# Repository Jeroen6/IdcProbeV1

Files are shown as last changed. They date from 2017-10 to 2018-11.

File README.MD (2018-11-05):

# IdcProbeV1
Invasive isolated DC Current probe based on Sensitec CMS3000

## What

This USB 5V powered current sensor should provide an relatively cheap way to safely scope AC or DC current.  
It should provide isolation up to 4 kV (rms), meaning it can measure anywhere in a circuit.

The high bandwidth and accuracy of the Sensitec module made it almost like a normal shunt.

Transfer ratio of the 5A and 15A unit would be 1A:1V and 1A:0.1V respectively.

## Challenges
The challenges involved in this project are powering the Sensitec sensor from a USB port, commonly found on most modern scopes.  
This required a high frequency (1.3 Mhz) DC-DC converter to create positive ands negative 12V for the sensor.  
Several prototypes have shown this is not an easy job, keeping ripple low is difficult with >1 MHz converters.

Due to the capacitance required for the DC-DC converter a high inrush current needs to be reduced on the USB input.

## Progress so far
So far two working prototypes have been made (photo) and used thoroughly this year, it was extremely useful!  
Several important changes to the circuit have been made, both to the DC-DC, the input current, and oscillation prevention on the output with long BNC cables.

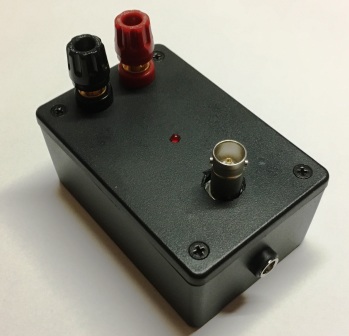
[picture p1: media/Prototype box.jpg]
photo of prototype
  
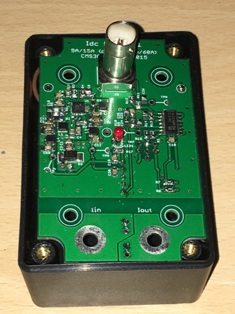
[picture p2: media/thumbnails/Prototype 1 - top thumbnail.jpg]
photo of prototype

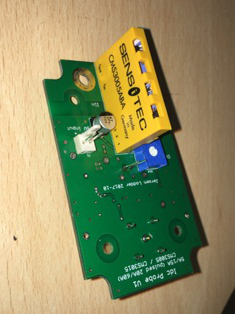
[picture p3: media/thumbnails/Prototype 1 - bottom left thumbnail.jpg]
photo of prototype
  
*(high-res in media folder)*

However, when (winter)time came to continue this project sad news arrived.  
[Sensitec discontinued the CMS and CDS current sensor families][1], with the [CFS1000][2] chip as alternative.

## Future
The CFS1000 is a more versatile product. Which is an advantage, but not if you required on the engineering and factory calibration of the CMS3000.
The CFS series requires development of an external sensing busbar and calibration procedure, both exceed my initial intended complexity of this project. But I might change my mind.

I will probably not persue development of this project, apart from assembling a few units for peronal use.  

*If someone has ideas to revive this project, let me know (make an issue or something)*

[1]: https://github.com/Jeroen6/IdcProbeV1/blob/master/doc/Sensitec%20-%20CMS3000%20-%20Current%20sensor%20discontinuation%20notice.pdf
[2]: https://github.com/Jeroen6/IdcProbeV1/blob/master/doc/Sensited%20-%20CFS1000%20-%20%20Integrated%20MagnetoResistive%20Current%20Sensor.pdf

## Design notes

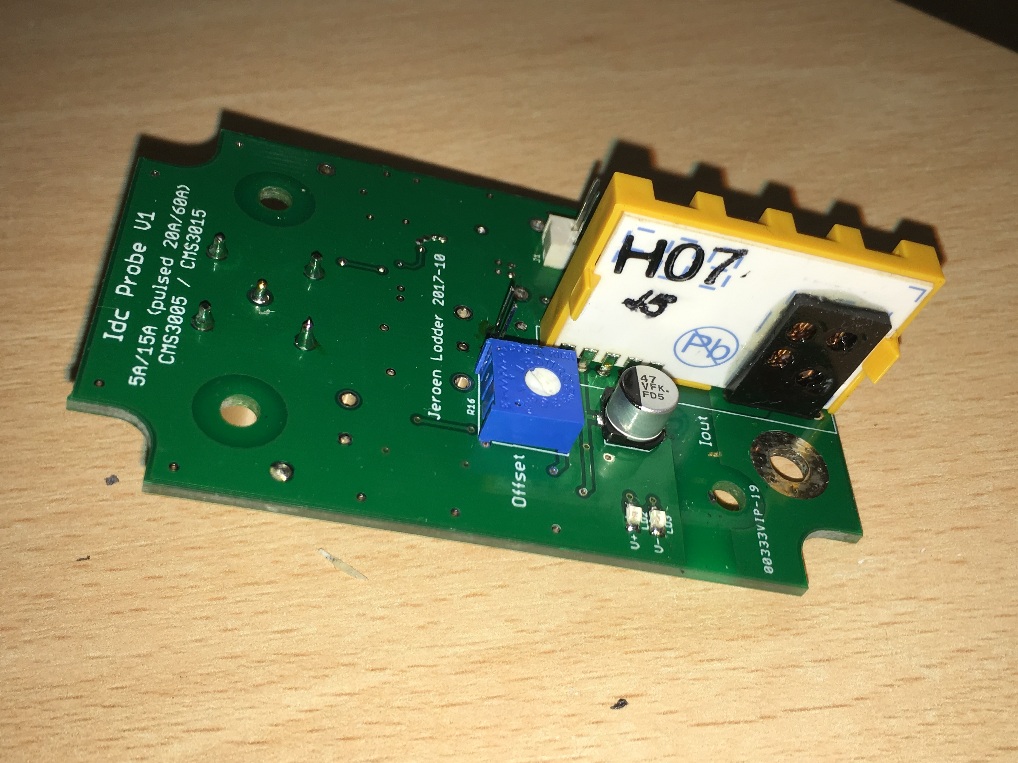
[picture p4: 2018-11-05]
media/Prototype 1 - bottom right.jpg

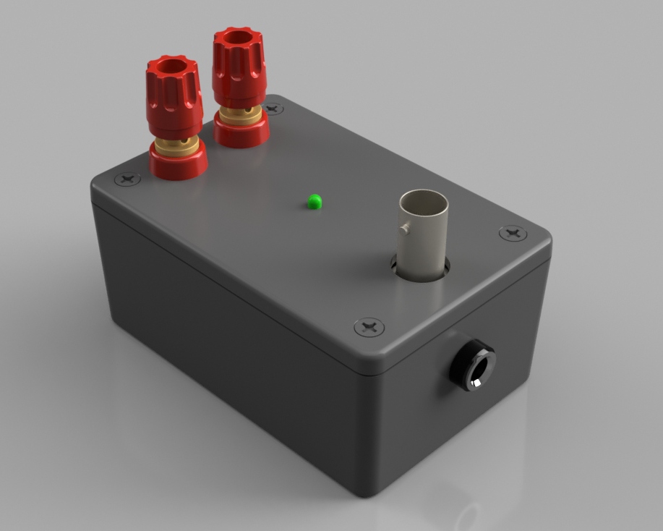
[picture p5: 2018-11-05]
media/IdcProbe Render.jpg

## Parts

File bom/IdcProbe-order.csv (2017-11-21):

Qty | Value | Device | Package | Parts | Description | MF | MPN | OC_FARNELL | OC_NEWARK | PACKAGE2 | SF_ID | SUPPLIER
1 |  | CMS3000_15A | CMS3015 | U3 | CMS3005
1 |  | CONN_02POLAR | MOLEX-1X2 | J1 | Multi connection point. Often used as Generic Header-pin footprint for 0.1 inch spaced/style header connections |  | TMK212AB7475KG-T |  |  |  | PRT-09918
1 |  | R-EU_R0805 | R0805 | R13 | RESISTOR
1 | 0 | R-EU_R0805 | R0805 | R22 | RESISTOR
1 | 0.5AT | FUSE_PTC-0805 | PTC0805 | F1 | Resettable PTC
1 | 1.8M | R-EU_R0805 | R0805 | R15 | RESISTOR
1 | 100 | R-EU_R0805I | R0805I | R2 | RESISTOR
1 | 100k | POT_MULTI | 3386-MULTI | R14 | 3/8 multi pot |  | 3386P-1-104LF
1 | 100k | R-EU_R0805 | R0805 | R21 | RESISTOR
1 | 10nF 16V X7R | C-EUC0805 | C0805 | C8 | CAPACITOR
1 | 15 / 33 | R-EU_R0805 | R0805 | R12 | RESISTOR
1 | 1K | R-EU_R0805 | R0805 | R16 | RESISTOR
1 | 1k | R-EU_R0805I | R0805I | R1 | RESISTOR
1 | 1uF 25V X5R | C-EUC0805 | C0805 | C1 | CAPACITOR
1 | 220nF | C-EUC0805 | C0805 | C10 | CAPACITOR
1 | 3.3nF / 2.2nF | C-EUC0805 | C0805 | C26 | CAPACITOR
1 | 4.7nF 50V C0G | C-EUC0805 | C0805 | C9 | CAPACITOR
1 | Green | LED3MM | LED3MM | LED1 | LED
1 | NCP361MUTBG | NCP36XMU | UDFN6_2X2 | U1 |  |  | TMK212AB7475KG-T
1 | PCB_HAMMOND_1591XXL | PCB_HAMMOND_1591XXL | HMD_MFG_1591XXL | H1 | Multiple PCB formats from Hammond MFG cases
1 | PMV45EN | PMV45EN | SOT23 | Q1 | PMV45EN Logic Level Trenchmos
1 | R141426 | R141426 | R141426 | X1 | BNC COAX CONNECTOR | FARNELL | R141426161 | 4195115 | 14J7919
1 | SMAJ12CA | TVS_BISMA | SMA_NOPOL | D1 | Collection of bidirectional TVS diodes
1 | TL074D | TL074D | SO14 | IC1 | OP AMP
1 | TPS65131RGET | TPS65131RGET | QFN50P400X400X100-25N | U2 | POSITIVE AND NEGATIVE OUTPUT DC-DC CONVERTER |  | TPS65131RGET | 1755480 | 44J2536 | VQFN-24 |  | Texas Instruments
2 |  | R-EU_R0805I | R0805I | R18
2 | 1000k | R-EU_R0805I | R0805I | R4
2 | 100k | R-EU_R0805I | R0805I | R3
2 | 47uF (EEEFK1V470P) | CPOL-EUD | PANASONIC_D | C23
2 | BANANA_SOCKETVERTICAL | BANANA_SOCKETVERTICAL | 4
2 | Green | LEDCHIP-LED0805 | CHIP-LED0805 | LED2
2 | Schottky 1A 20V | DIODE-SOD323-R | SOD323-R | D2
2 | TESTPOINT_GND | TESTPOINT_GND | PROBE_POINT | TP7
3 |  | TESTPOINT | TESTHOOK | TP1
3 | 3.9k | R-EU_R0805I | R0805I | R7
4 | 10k | R-EU_R0805I | R0805I | R10
4 | 3.3uH (SRN3015) | INDUCTOR_VLS3015 | VLS3015 | L1
5 |  | C-EUC0805 | C0805 | C11
6 | 100nF | C-EUC0805 | C0805 | C2
13 | 4.7uF 25V X5R | C-EUC0805 | C0805 | C4

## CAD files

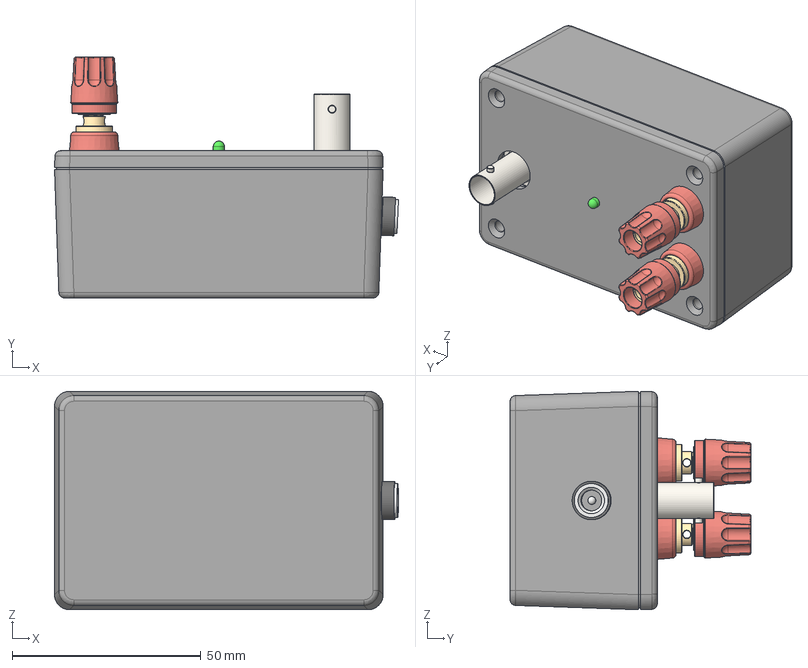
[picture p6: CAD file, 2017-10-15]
enclosure/IdcProbe model v32.step
91.1 x 63.8 x 57.9 mm
DJ Jack 2,1mm panel mount v1
Hirschmann Banana x 2
1591XXL BOX
1591XXL LID
PCB Bottom
PCB Screw x 4
LED
BNC
CMS3005

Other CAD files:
enclosure/Hirschmann PKI 10 A Banana plug v16.f3d
enclosure/IdcProbe model v32.f3d
enclosure/IdcProbe model v32.iges

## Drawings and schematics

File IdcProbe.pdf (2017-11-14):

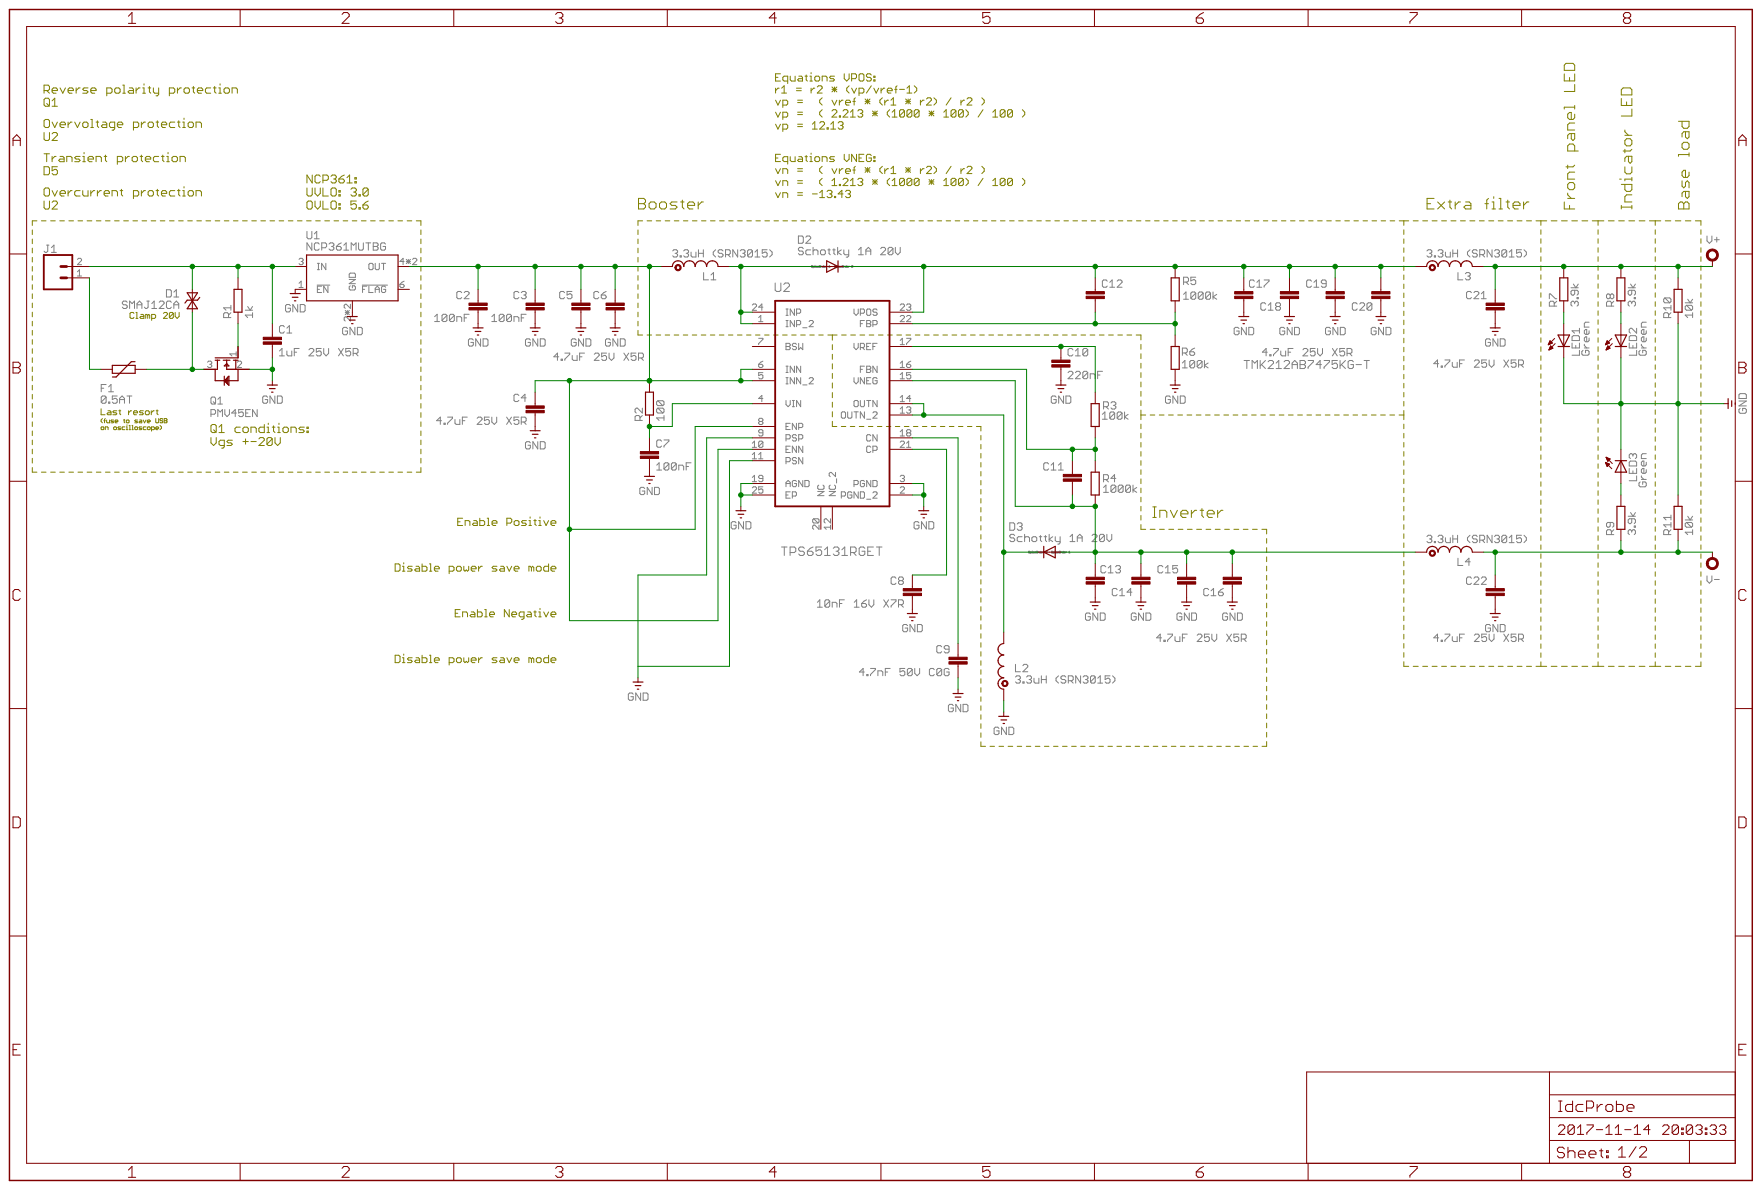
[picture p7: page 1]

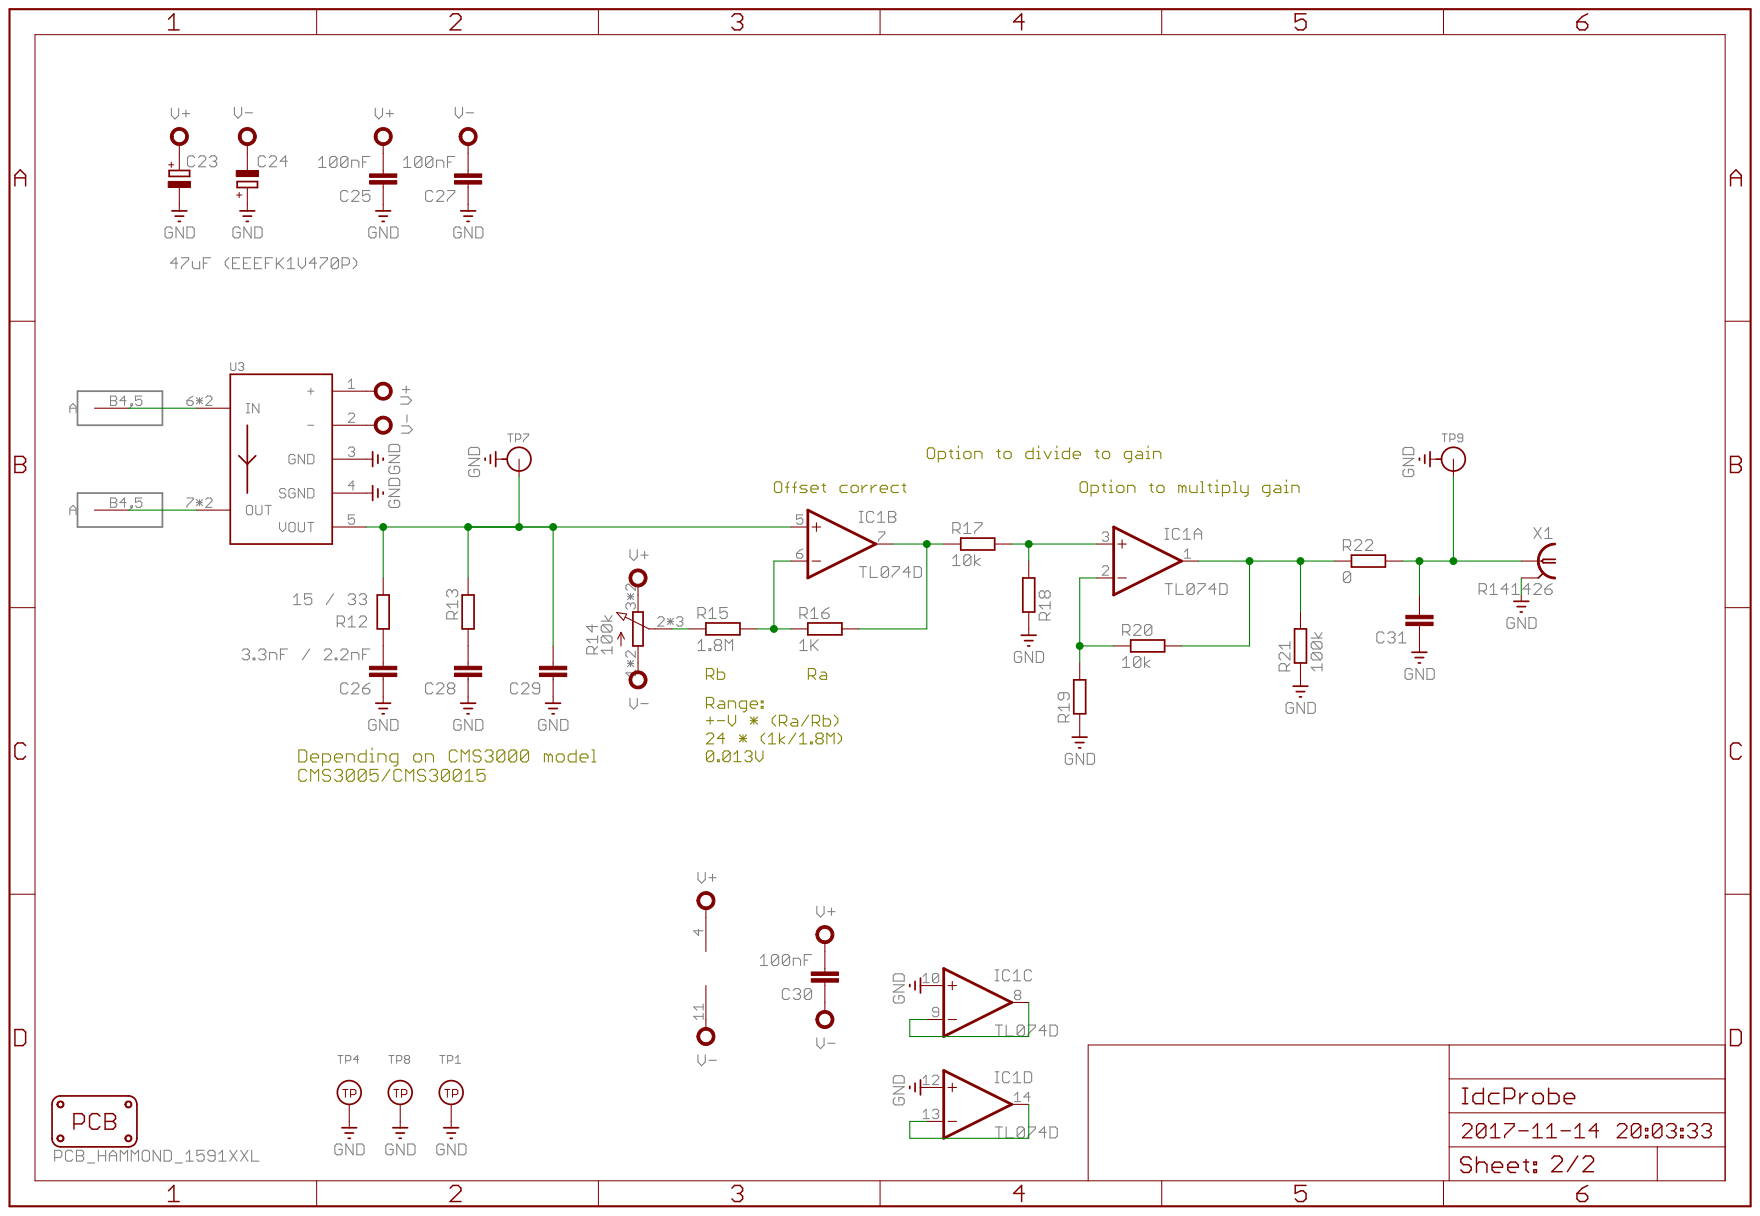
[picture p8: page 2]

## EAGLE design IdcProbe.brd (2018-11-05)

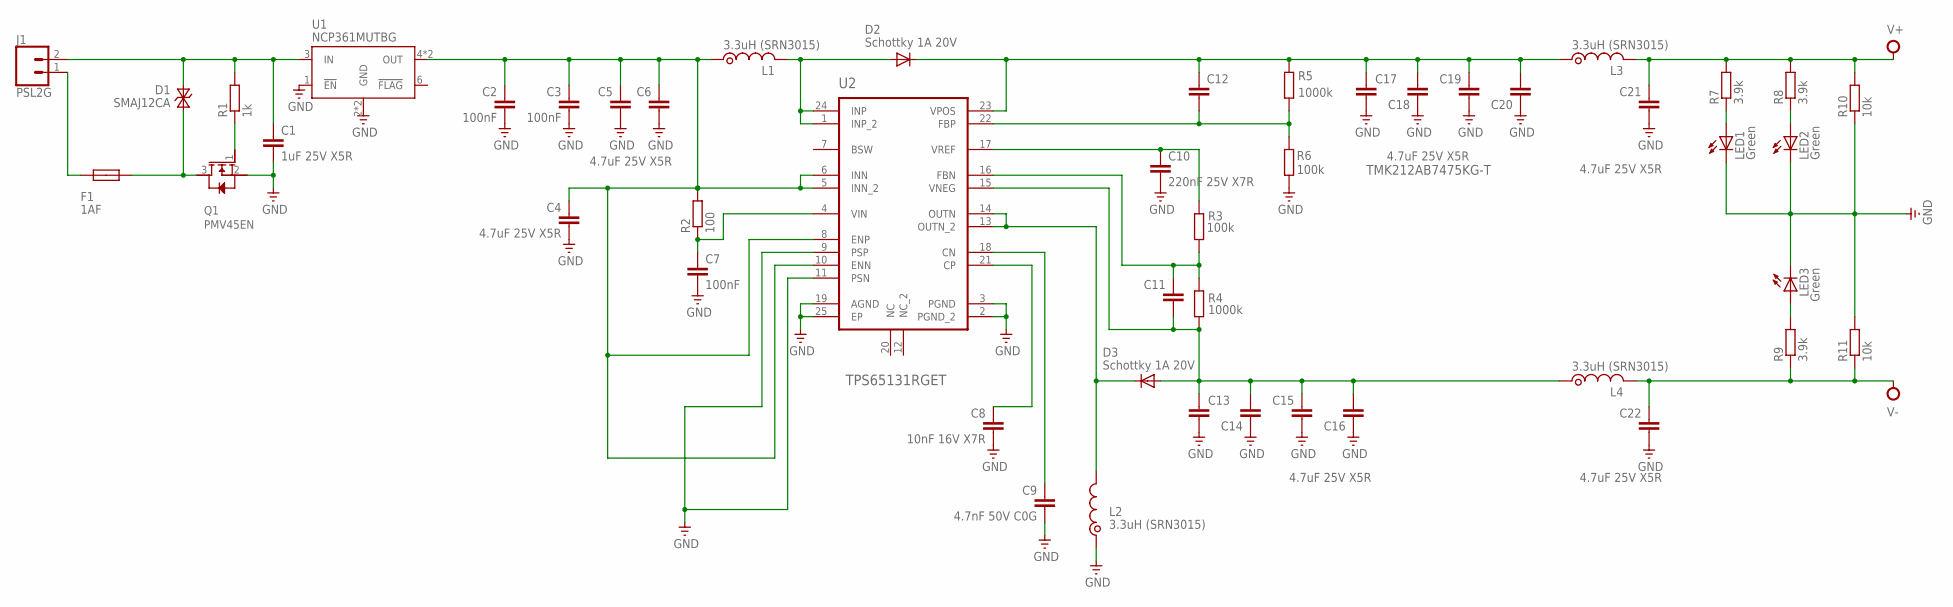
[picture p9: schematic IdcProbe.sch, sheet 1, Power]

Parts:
C1: 1uF 25V X5R; C0805; MPN TMK212AB7475KG-T
C2, C3, C7: 100nF; C0805
C4, C5, C6, C13, C14, C15, C16, C17, C18, C19, C20, C21, C22: 4.7uF 25V X5R; C0805; MPN TMK212AB7475KG-T
C8: 10nF 16V X7R; C0805
C9: 4.7nF 50V C0G; C0805
C10: 220nF 25V X7R; C0805
C11, C12: C-EUC0805; C0805
D1: SMAJ12CA; SMA_NOPOL
D2, D3: Schottky 1A 20V; SOD323-R; MPN PMEG4010BEA
F1: 1AF; 1206_HV
J1: PSL2G; MOLEX-1X2
L1, L2, L3, L4: 3.3uH (SRN3015); VLS3015
LED1: Green; LED3MM
LED2, LED3: Green; CHIP-LED0805
Q1: PMV45EN; SOT23
R1: 1k; R0805I
R2: 100; R0805I
R3, R6: 100k; R0805I
R4, R5: 1000k; R0805I
R7, R8, R9: 3.9k; R0805I
R10, R11: 10k; R0805I
U1: NCP361MUTBG; UDFN6_2X2; MPN TMK212AB7475KG-T
U2: TPS65131RGET; QFN50P400X400X100-25N

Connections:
CN: C9.1, U2.18 (CN)
CP: C8.1, U2.21 (CP)
FBN: C11.1, R3.1, R4.1, U2.16 (FBN)
FBP: C12.2, R5.1, R6.2, U2.22 (FBP)
GND: C1.2, C2.2, C3.2, C4.2, C5.2, C6.2, C7.2, C8.2, C9.2, C10.2, C13.2, C14.2, C15.2, C16.2, C17.2, C18.2, C19.2, C20.2, C21.2, C22.2, L2.1, LED1.K (C), LED2.C, LED3.C, Q1.2 (S), R6.1, R10.1, R11.2, U1.1 (!EN), U1.2 (GND), U1.7 (GND), U2.2 (PGND_2), U2.3 (PGND), U2.9 (PSP), U2.11 (PSN), U2.19 (AGND), U2.25 (EP); also elsewhere on the board
INP: D2.A, L1.2, U2.1 (INP_2), U2.24 (INP)
unnamed: LED2.A, R8.1
unnamed: LED3.A, R9.2
unnamed: LED1.A, R7.1
unnamed: C1.1, D1.2 (C), J1.2, R1.2, U1.3 (IN)
unnamed: D1.1 (A), F1.P$1, Q1.3 (D)
unnamed: Q1.1 (G), R1.1
unnamed: F1.P$2, J1.1
OUTN: D3.C, L2.2, U2.13 (OUTN_2), U2.14 (OUTN)
RV+: C12.1, C17.1, C18.1, C19.1, C20.1, D2.C, L3.1, R5.2, U2.23 (VPOS)
RV-: C11.2, C13.1, C14.1, C15.1, C16.1, D3.A, L4.1, R4.2, U2.15 (VNEG)
V+: C21.1, L3.2, R7.2, R8.2, R10.2; also elsewhere on the board
V-: C22.1, L4.2, R9.1, R11.1; also elsewhere on the board
VI: C2.1, C3.1, C4.1, C5.1, C6.1, L1.1, R2.2, U1.4 (OUT), U1.5 (OUT), U2.5 (INN_2), U2.6 (INN), U2.8 (ENP), U2.10 (ENN)
VIN: C7.1, R2.1, U2.4 (VIN)
VREF: C10.1, R3.2, U2.17 (VREF)

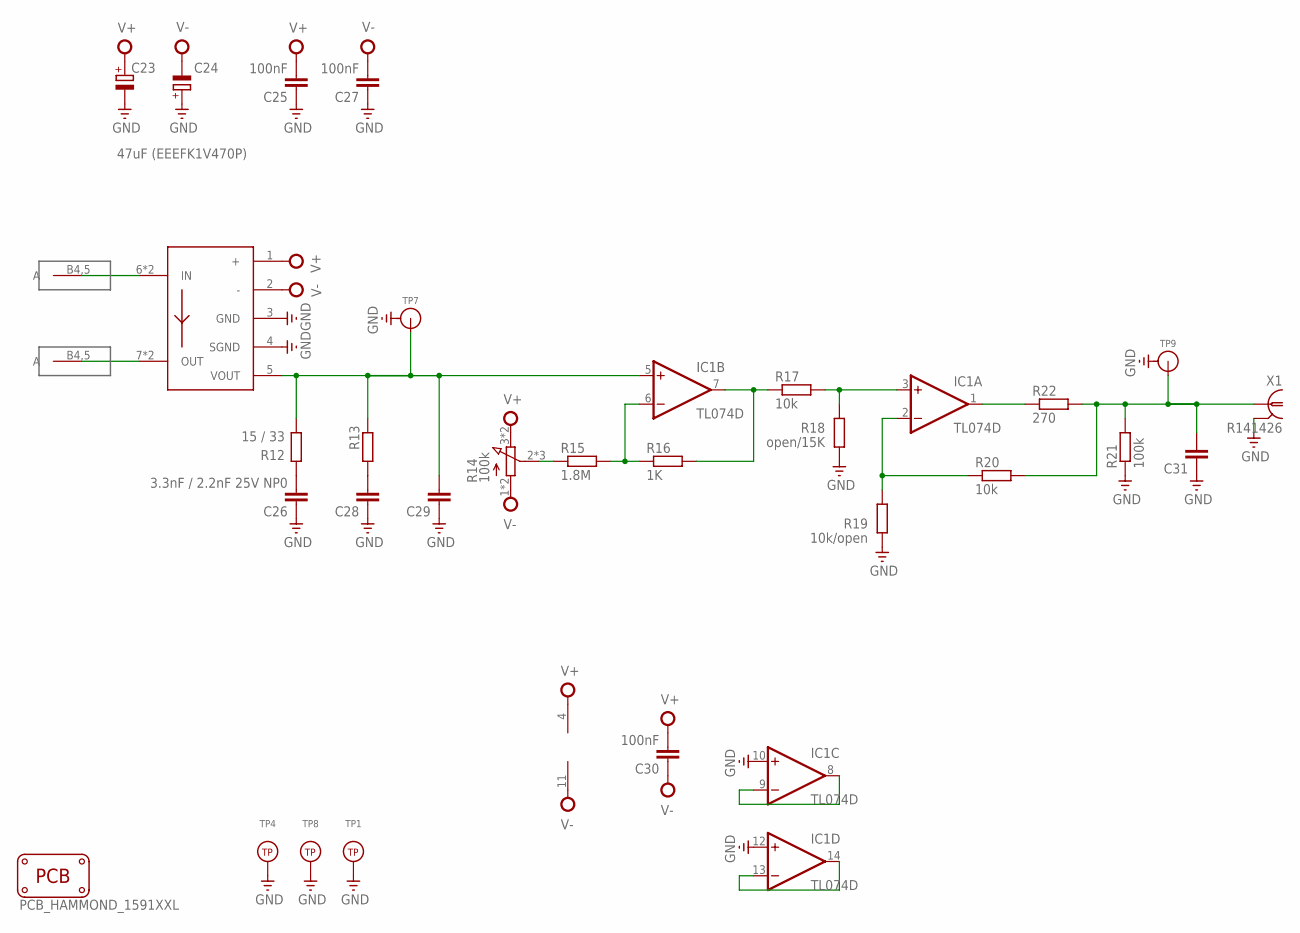
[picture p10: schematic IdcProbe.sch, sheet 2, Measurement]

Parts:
C23, C24: 47uF (EEEFK1V470P); PANASONIC_D
C25, C27, C30: 100nF; C0805
C26: 3.3nF / 2.2nF 25V NP0; C0805
C28, C29, C31: C-EUC0805; C0805
H1: PCB_HAMMOND_1591XXL; HMD_MFG_1591XXL
IC1: TL074D; SO14
P1, P2: BANANA_SOCKETVERTICAL; 4,5-PAD
R12: 15 / 33; R0805
R13: R-EU_R0805; R0805
R14: 100k; 3386-MULTI; MPN 3386P-1-104LF
R15: 1.8M; R0805
R16: 1K; R0805
R17, R20: 10k; R0805I
R18: open/15K; R0805I
R19: 10k/open; R0805I
R21: 100k; R0805
R22: 270; R0805
TP1, TP4, TP8: TESTPOINT; TESTHOOK
TP7, TP9: TESTPOINT_GND; PROBE_POINT
U3: CMS3005; CMS3015
X1: R141426

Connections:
GND: C23.-, C24.+, C25.1, C26.1, C27.1, C28.1, C29.1, C31.1, IC1.10 (+IN), IC1.12 (+IN), R18.1, R19.1, R21.1, TP1.TP, TP4.TP, TP7.GND, TP8.TP, TP9.GND, U3.3 (GND), U3.4 (SGND), X1.2, X1.3 (2), X1.4 (2), X1.5 (2); also elsewhere on the board
unnamed: IC1.7 (OUT), R16.2, R17.1
unnamed: IC1.6 (-IN), R15.2, R16.1
unnamed: P1.B4,5, U3.6 (IN), U3.6' (IN)
unnamed: P2.B4,5, U3.7 (OUT), U3.7' (OUT)
unnamed: IC1.8 (OUT), IC1.9 (-IN)
unnamed: IC1.13 (-IN), IC1.14 (OUT)
unnamed: C26.2, R12.2
unnamed: C28.2, R13.2
unnamed: C31.2, R20.2, R21.2, R22.2, TP9.TP, X1.1
unnamed: C29.2, IC1.5 (+IN), R12.1, R13.1, TP7.TP, U3.5 (VOUT)
unnamed: IC1.2 (-IN), R19.2, R20.1
unnamed: R14.2 (SW), R14.5 (SW), R14.7 (SW), R15.1
unnamed: IC1.3 (+IN), R17.2, R18.2
unnamed: IC1.1 (OUT), R22.1
V+: C23.+, C25.2, C30.2, IC1.4 (V+), R14.3 (CW), R14.6 (CW), U3.1 (+); also elsewhere on the board
V-: C24.-, C27.2, C30.1, IC1.11 (V-), R14.1 (CCW), R14.4 (CCW), U3.2 (-); also elsewhere on the board

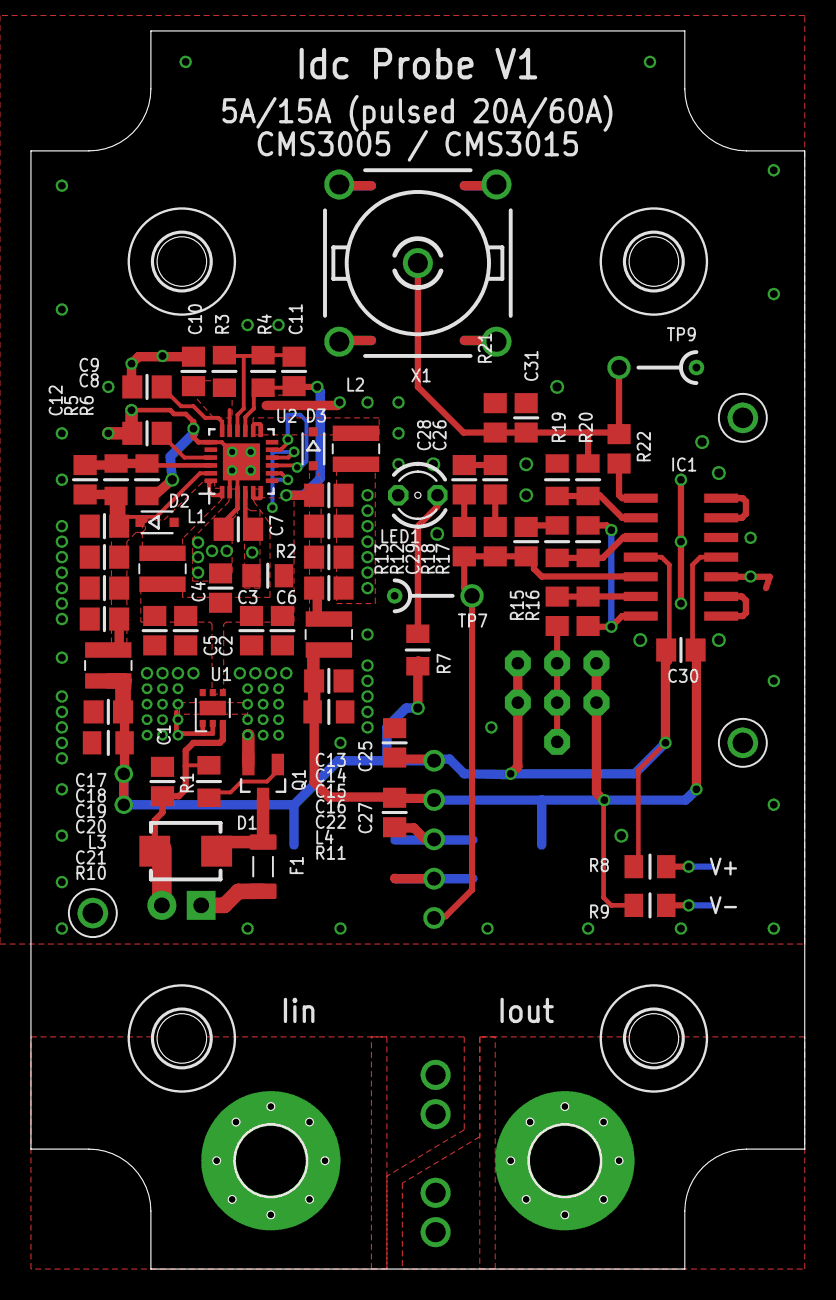
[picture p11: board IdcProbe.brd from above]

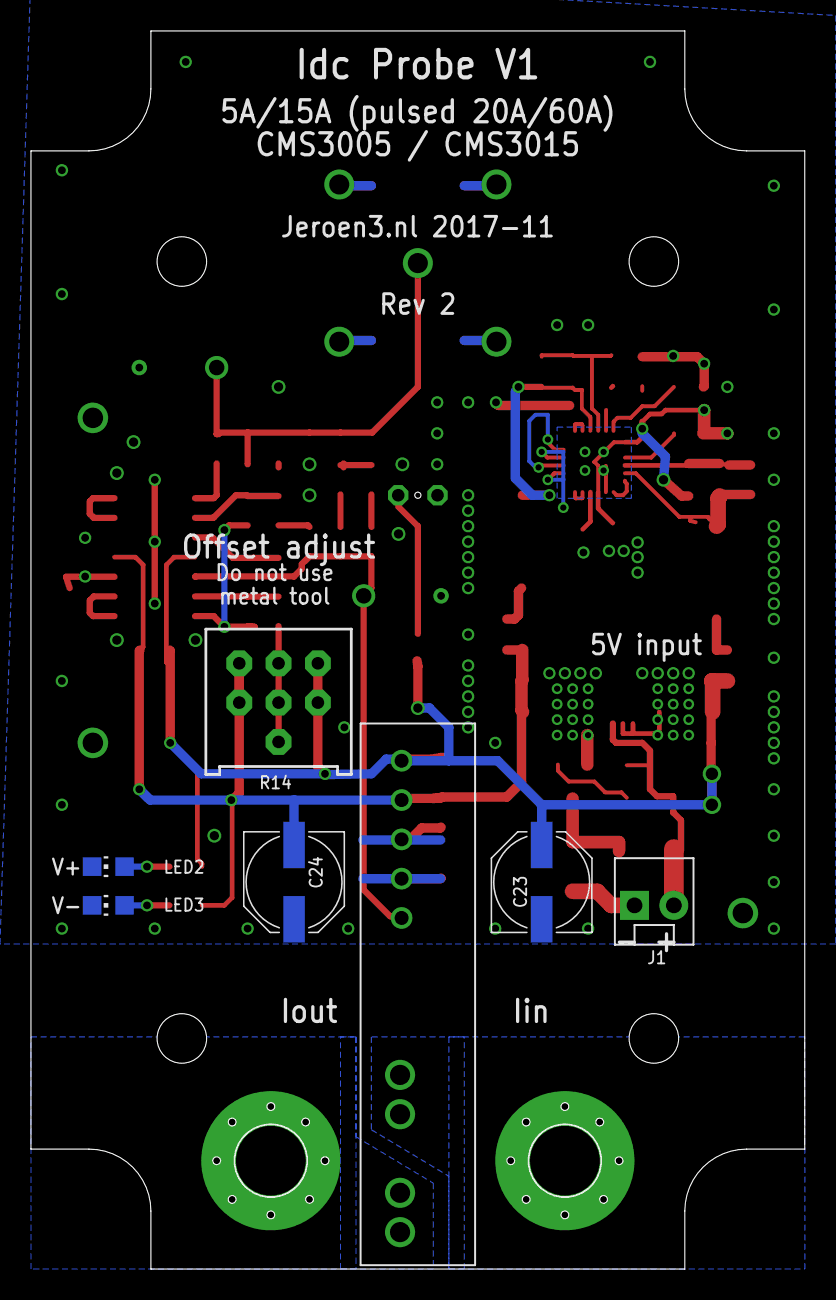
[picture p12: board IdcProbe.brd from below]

Board: 2 copper layers, 50.0 x 80.0 mm, 79 parts (7 on the bottom side), 35 nets.

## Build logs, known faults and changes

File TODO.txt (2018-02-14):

Status:
- = Planned.
X = In progress, some work done.
* = Done.
? = Not sure if worth the effort or useful at all.
N = Decided against.

Prepend versions on list from top (oldest at bottom)
----------
- Fix oscillation on capacitive load. Add load resistance.
- Measure significance of inrush on plug in.
- Test NCP360, since NCP361 with current limit will turn off due to inrush.
- Add fuse if NCP360 is used.

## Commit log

2017-11-08 Update smps
    [IdcProbe.brd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]
2017-11-12 Update
    - Update SMPS
    - Add supply protection
    - Add documentation
    - Started with attributes for BOM.
    - Added divide gain option
    - Printed pdf and generated gerbers
    [IdcProbe.brd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]
2017-11-14 Update
    Added fuse.
    Renumbered schematic.
    Created pdf and gerber for review.
    [IdcProbe.brd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]
2017-11-14 Shrunk mounting holes, added LED drill alignment hole
    [IdcProbe.brd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]
2017-11-21 ordered rev2
    [Calculations.xlsx, IdcProbe-order.csv, IdcProbe-order.xlsx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]
2018-11-05 Accumulated fixes during testing for version 1.2
    [IdcProbe.brd, IdcProbe.sch]

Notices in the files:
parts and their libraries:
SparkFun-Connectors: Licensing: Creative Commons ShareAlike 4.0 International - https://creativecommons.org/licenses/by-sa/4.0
